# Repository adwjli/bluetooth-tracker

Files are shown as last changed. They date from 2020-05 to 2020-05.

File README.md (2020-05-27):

# Bluetooth Tracker

## Introduction
A Bluetooth Tracker inspired by the Tile Mate Bluetooth Tracker, built around the Nordic nRF51822 Bluetooth transceiver. The device can be programmed to pair with any Android or iOS mobile device via a mobile app.

The design of the trace antenna was provided by Texas Instrument in Application Note AN043. It is an Inverted F Antenna (IFA) with a matched 50 Ohm characteristic impedance at 2.4GHz. The device is capable of up to 4dBm of transmit power.

## Gallery

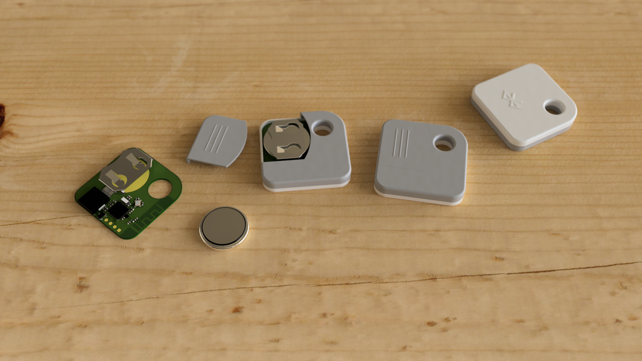
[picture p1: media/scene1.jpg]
Bluetooth Tracker PCB with enclosure.


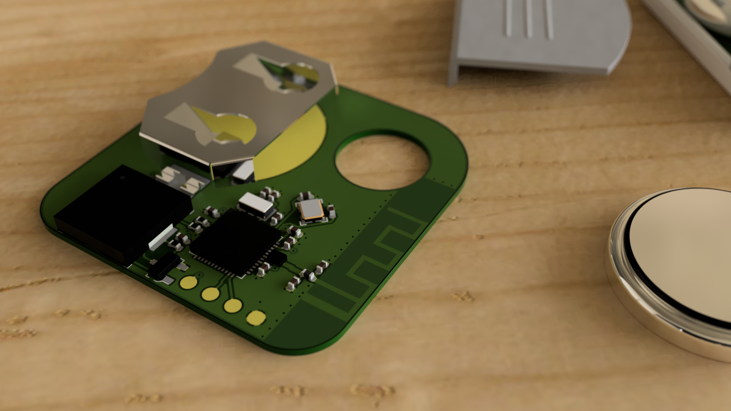
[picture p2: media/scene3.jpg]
Bleutooth Tracker PCB close up.


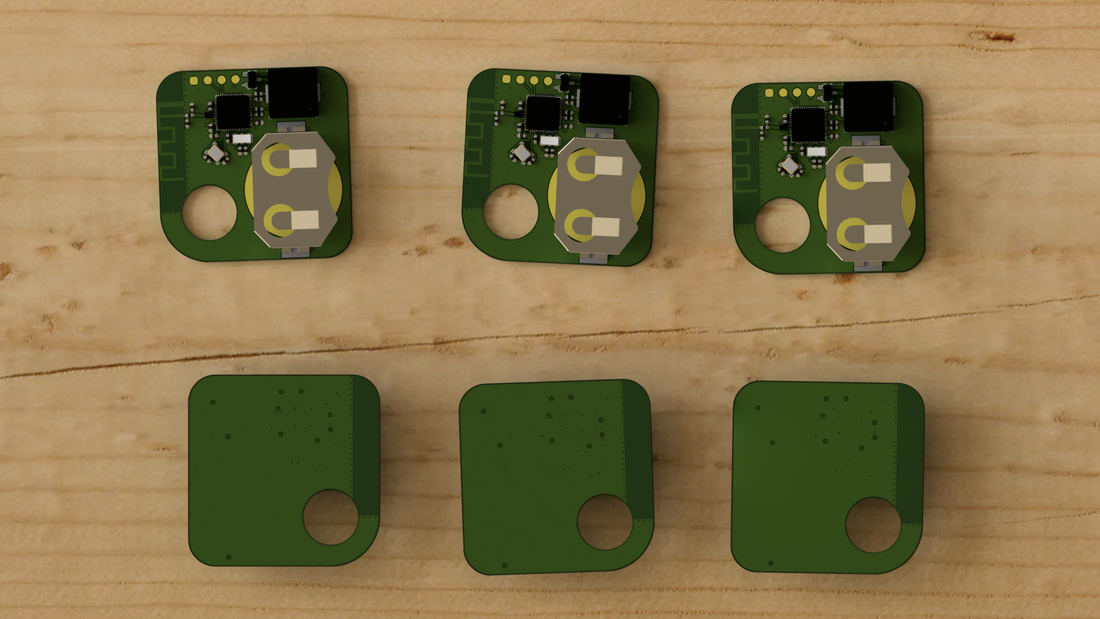
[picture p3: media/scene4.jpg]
Bluetooth Tracker PCB, top and bottom.


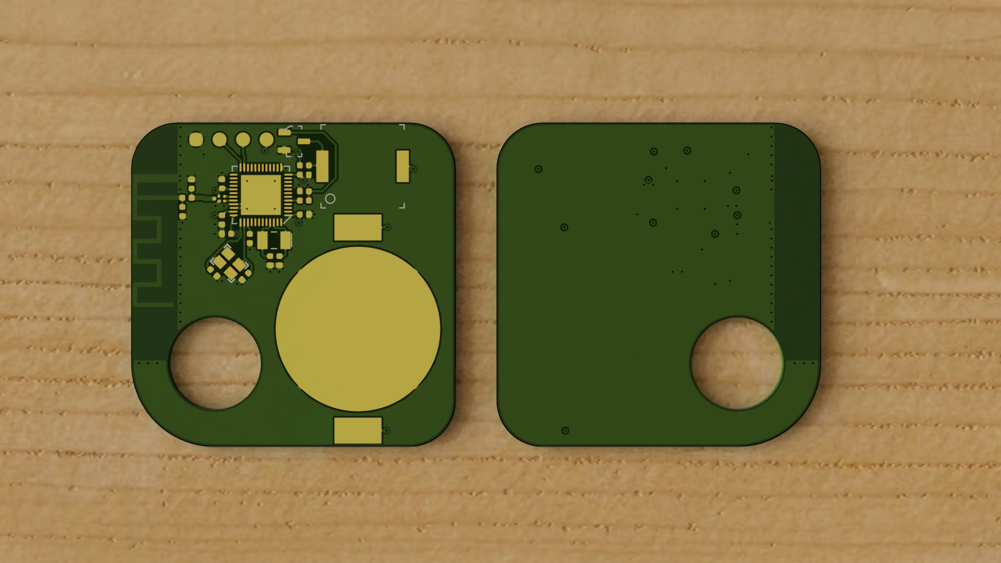
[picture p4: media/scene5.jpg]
Bluetooth Tracker PCB, top and bottom, bare PCB.


## Copper Layers

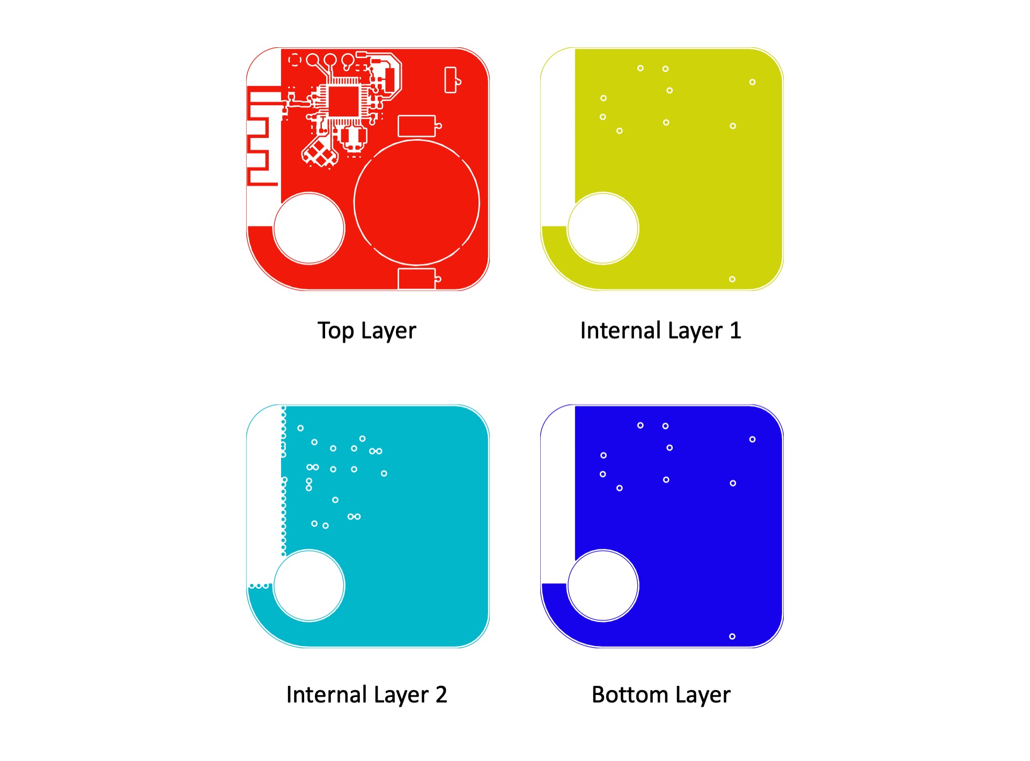
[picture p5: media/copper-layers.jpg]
PCB copper layers.


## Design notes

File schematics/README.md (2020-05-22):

# Schematics

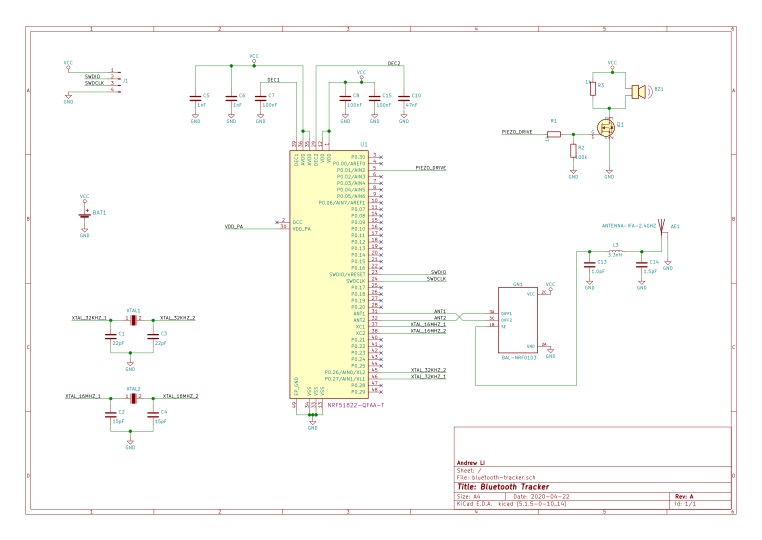
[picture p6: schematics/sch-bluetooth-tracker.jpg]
Schematics.


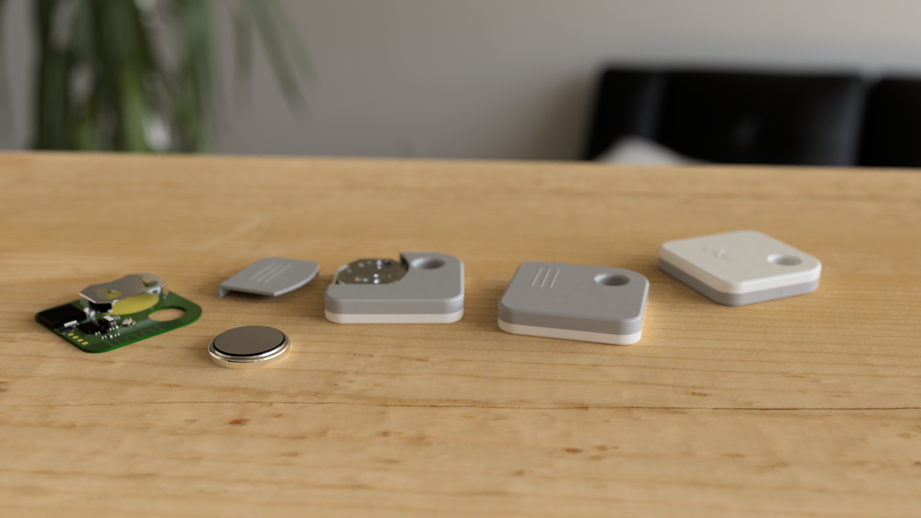
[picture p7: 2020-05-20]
media/scene2.jpg

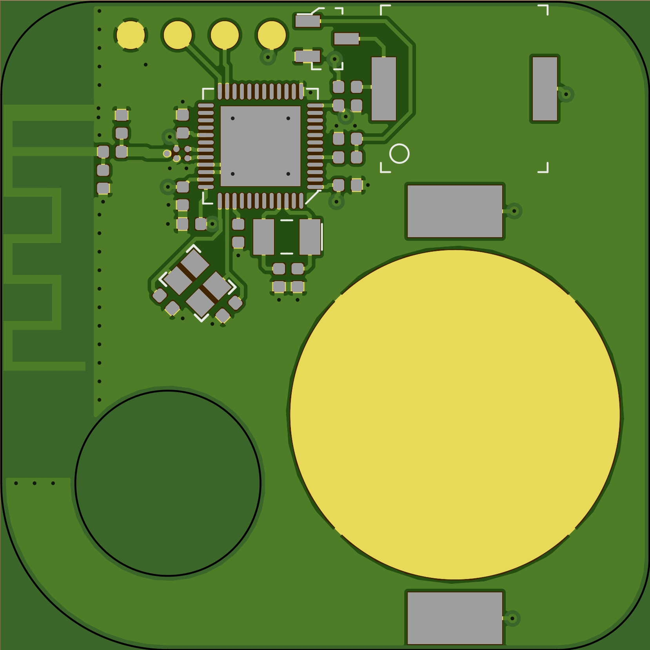
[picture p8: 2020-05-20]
raster/bluetooth-tracker-Front.png

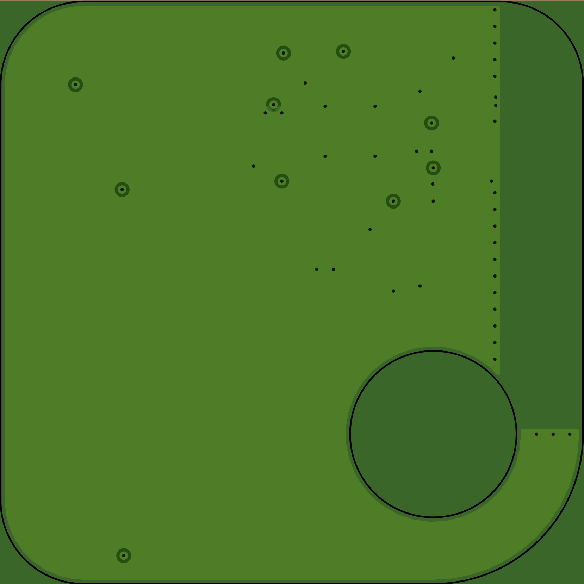
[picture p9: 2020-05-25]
raster/bluetooth-tracker-Back-bare.png

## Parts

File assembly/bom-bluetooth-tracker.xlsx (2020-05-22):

Reference | Quantity | Value | MPN | Manufacturer | Description
BAT1 | 1 | ~ | BK-912 | MPD (Memory Protection Devices) | BATTERY RETAINER COIN 20MM SMD
BZ1 | 1 | ~ | PKMCS0909E4000-R1 | Murata | AUDIO PIEZO TRANSDUCER 12.5V SMD
C1 C3 | 2 | 22pF | GCM1555C1H220FA16D | Murata | CAP CER 22PF 50V C0G/NP0 0402
C10 | 1 | 47nF | GRM155R71H473KE14D | Murata | CAP CER 0.047UF 50V X7R 0402
C13 | 1 | 1.0pF | GCM1555C1H1R0CA16J | Murata | CAP CER 1PF 50V C0G/NP0 0402
C14 | 1 | 1.5pF | GCM1555C1H1R5JA16D | Murata | CAP CER 1.5PF 50V C0G/NP0 0402
C15 C8 C7 | 3 | 100nF | GRM155R71E104KE14J | Murata | CAP CER 0.1UF 25V X7R 0402
C4 C2 | 2 | 15pF | GJM1555C1H150FB01D | Murata | CAP CER 15PF 50V C0G/NP0 0402
C6 C5 | 2 | 1nF | GCM155R71H102KA37D | Murata | CAP CER 1000PF 50V X7R 0402
GN1 | 1 | BAL-NRF01D3 | BAL-NRF01D3 | STMicroelectronics | BALUN 2.4GHZ-2.54GHZ 5WFBGA
L3 | 1 | 3.3nH | LQP15MN3N3W02D | Murata | 3.3nH Unshielded Thick Film Inductor 190mA 400mOhm Max 0402 (1005 Metric)
Q1 | 1 | ~ | FDV301N | ON Semiconductor | MOSFET N-CH 25V 220MA SOT-23
R2 | 1 | 100kΩ | RC0402FR-07100KL | Yageo | RES SMD 100K OHM 1% 1/16W 0402
R3 R1 | 2 | 1kΩ | RC0402FR-071KP | Yageo | RES SMD 1K OHM 1% 1/16W 0402
U1 | 1 | ~ | NRF51822-QFAA-T | Nordic Semiconductor ASA | IC RF TXRX+MCU BLUETOOTH 48VFQFN
XTAL1 | 1 | ~ | ECS-.327-12.5-34B-TR | ECS Inc. | CRYSTAL 32.7680KHZ 12.5PF SMD
XTAL2 | 1 | ~ | NX2520SA-16MHZ-STD-CSW-5 | NDK America, Inc. | CRYSTAL 16.0000MHZ 8PF SMD

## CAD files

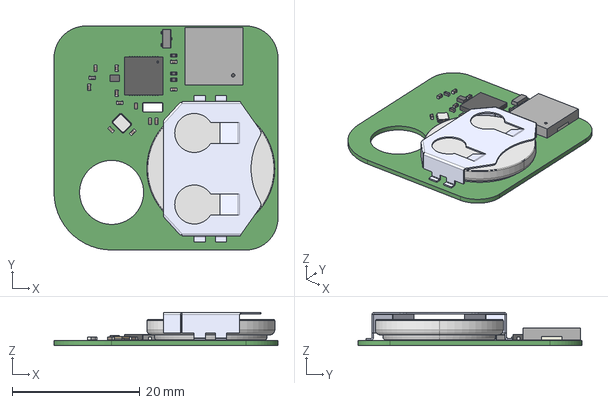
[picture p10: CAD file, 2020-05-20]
step/bluetooth-tracker.step
35.0 x 35.0 x 5.17 mm

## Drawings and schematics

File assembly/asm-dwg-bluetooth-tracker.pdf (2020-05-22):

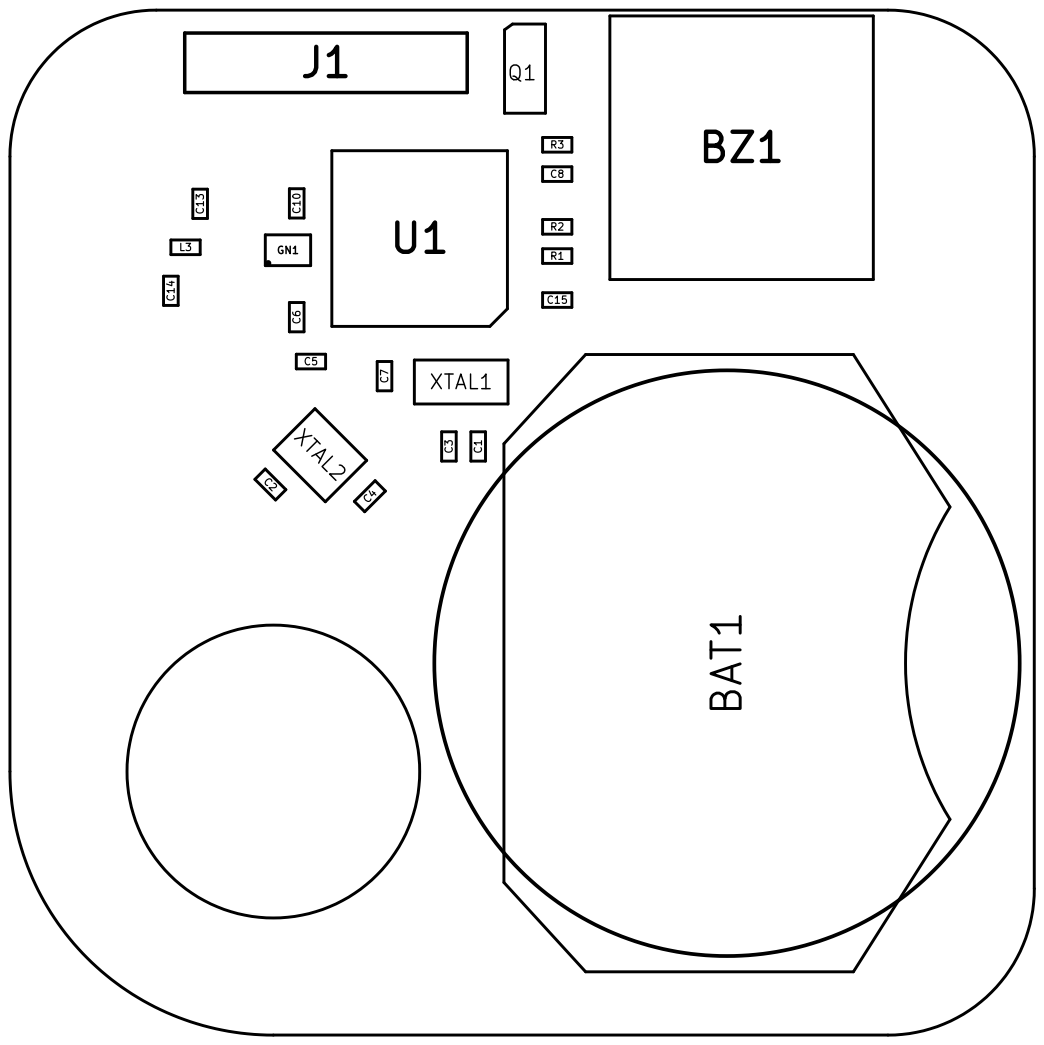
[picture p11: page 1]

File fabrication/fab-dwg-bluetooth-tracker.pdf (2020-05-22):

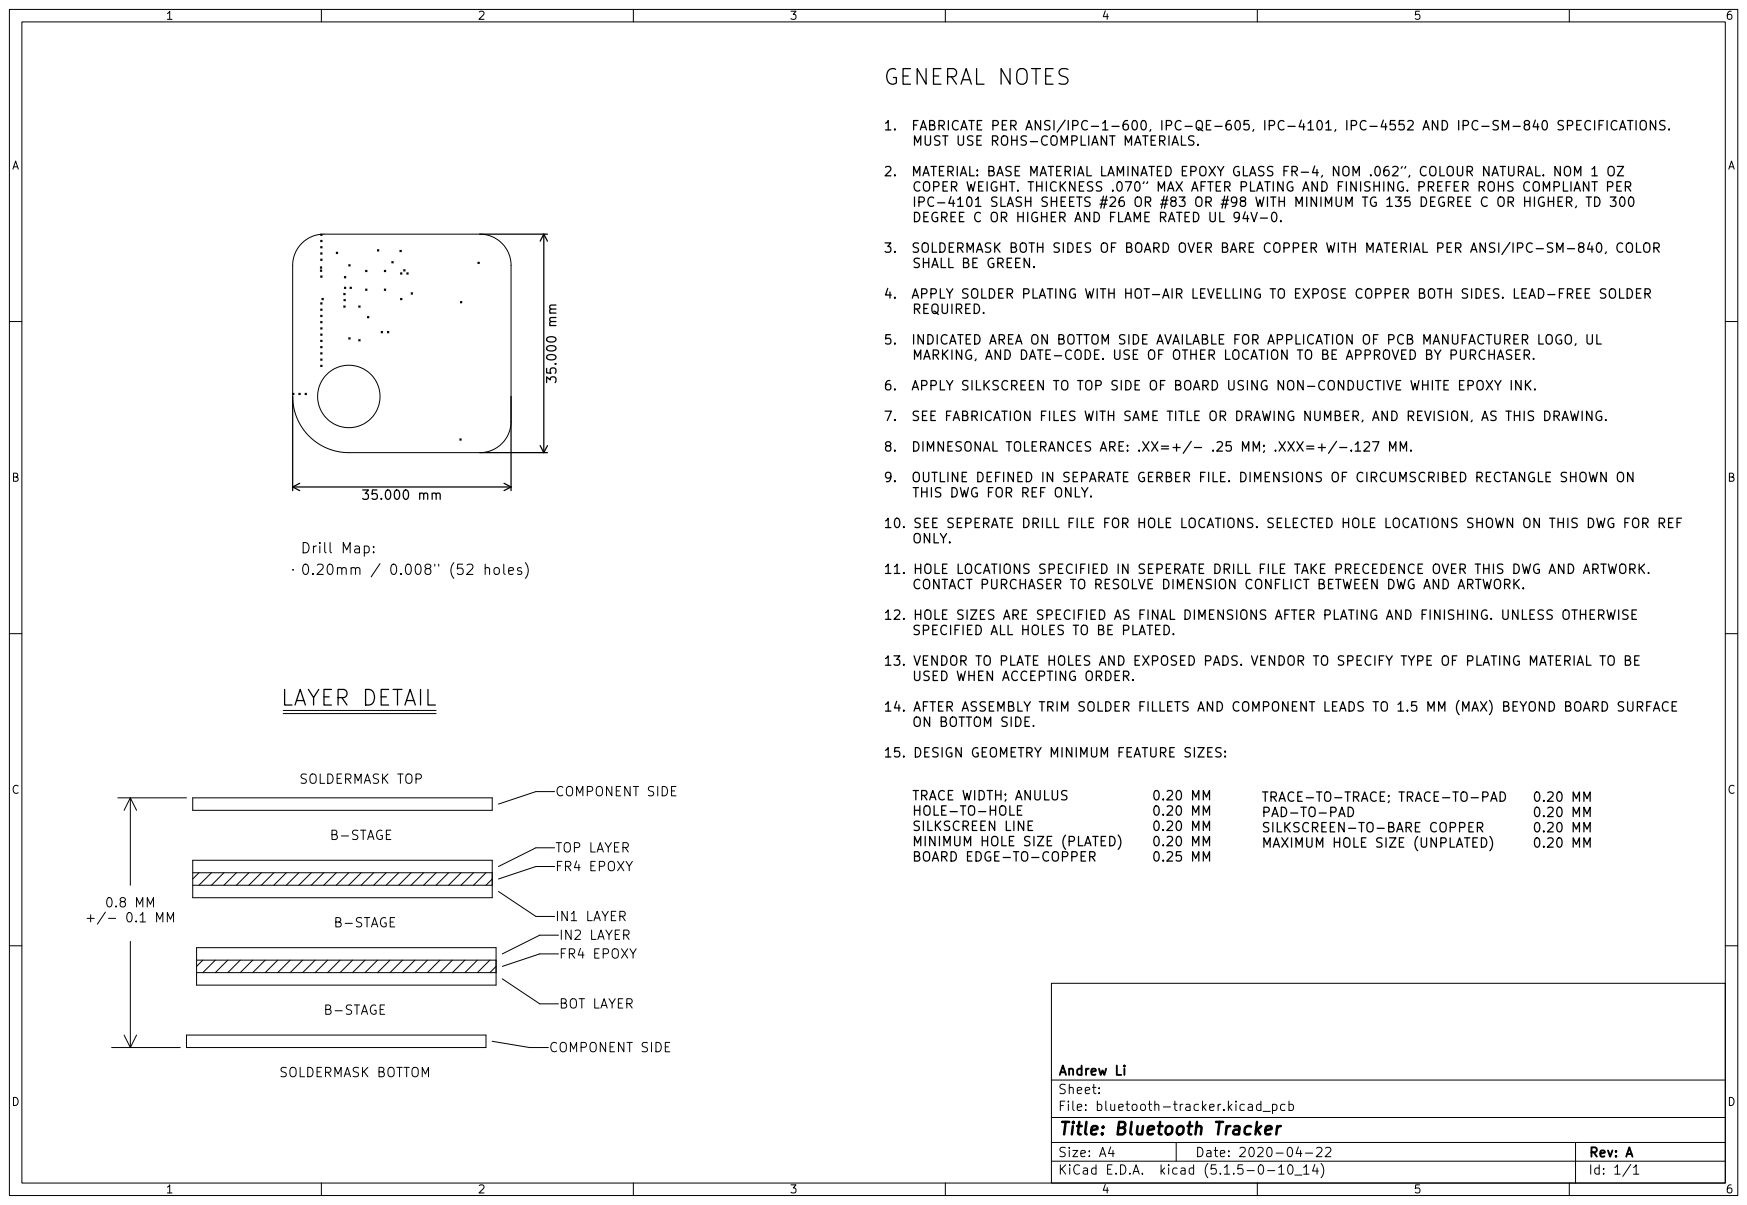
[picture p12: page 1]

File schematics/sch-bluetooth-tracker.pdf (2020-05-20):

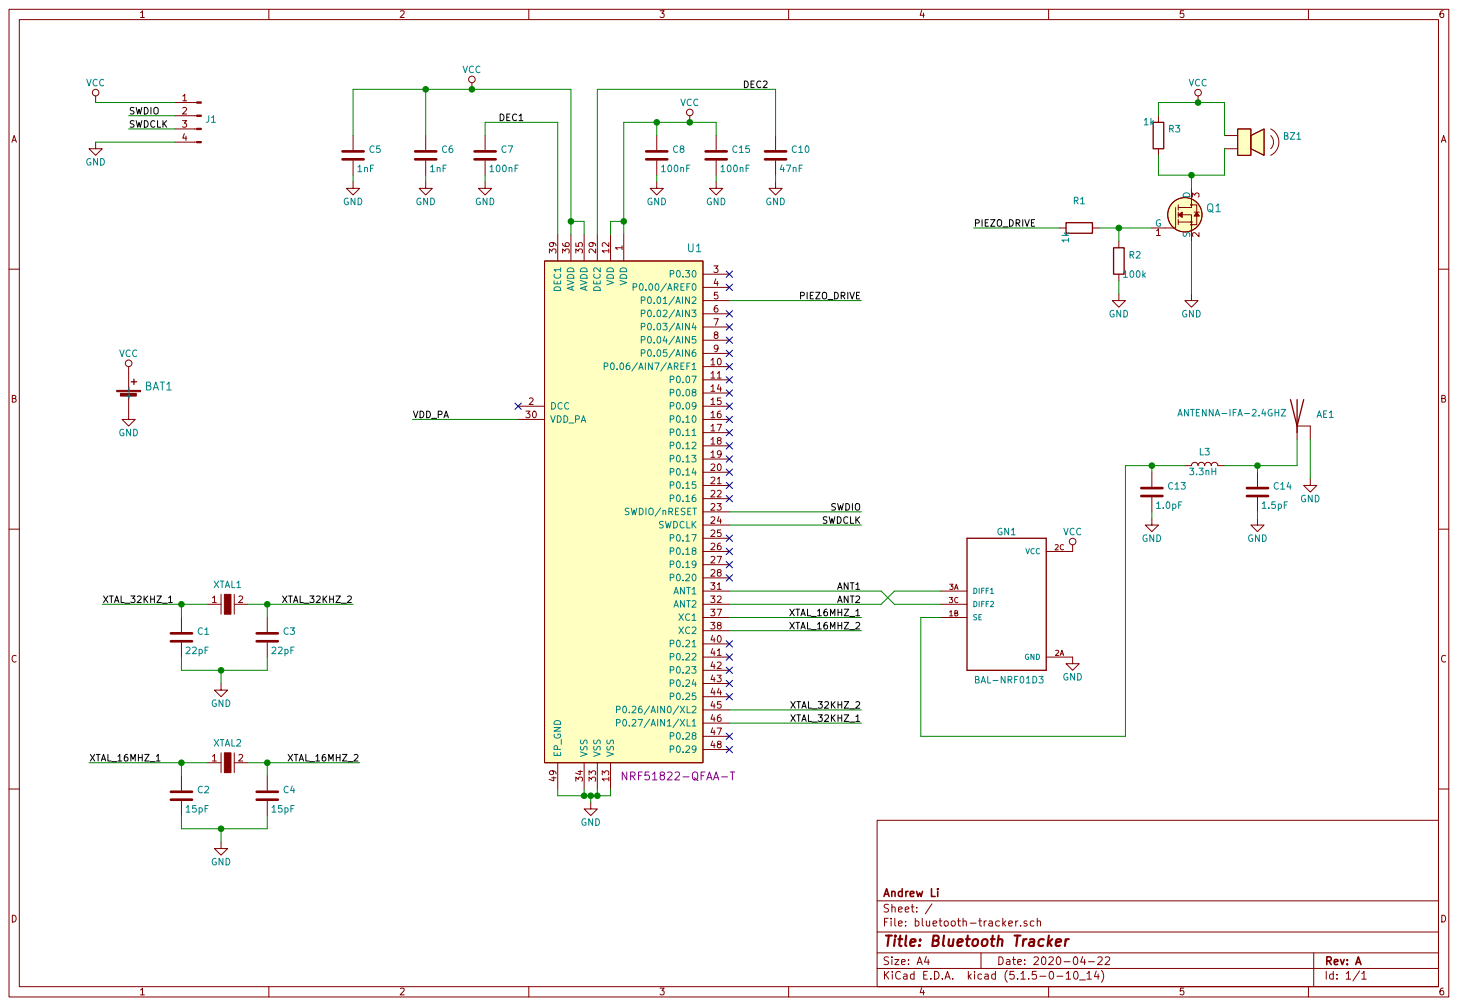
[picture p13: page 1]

1 P0.06/AIN7/AREF1 10 P0.07 11 VDD 12 VSS 13 P0.08 14 P0.09 15 P0.10 16 P0.11 17 P0.12 18 P0.13 19 DCC 2 P0.14 20 P0.15 21 P0.16 22 SWDIO/nRESET 23 SWDCLK 24 P0.17 25 P0.18 26 P0.19 27 P0.20 28 DEC2 29 P0.30 3 VDD_PA 30 ANT1 31 ANT2 32 VSS 33 VSS 34 AVDD 35 AVDD 36 XC1 37 XC2 38 DEC1 39 P0.00/AREF0 4 P0.21 40 P0.22 41 P0.23 42 P0.24 43 P0.25 44 P0.26/AIN0/XL2 45 P0.27/AIN1/XL1 46 P0.28 47 P0.29 48 EP_GND 49 P0.01/AIN2 5 P0.02/AIN3 6 P0.03/AIN4 7 P0.04/AIN5 8 P0.05/AIN6 9 U1 NRF51822-QFAA-T

Id: 1/1 Title: Bluetooth Tracker File: bluetooth-tracker.sch Sheet: / Andrew Li GND

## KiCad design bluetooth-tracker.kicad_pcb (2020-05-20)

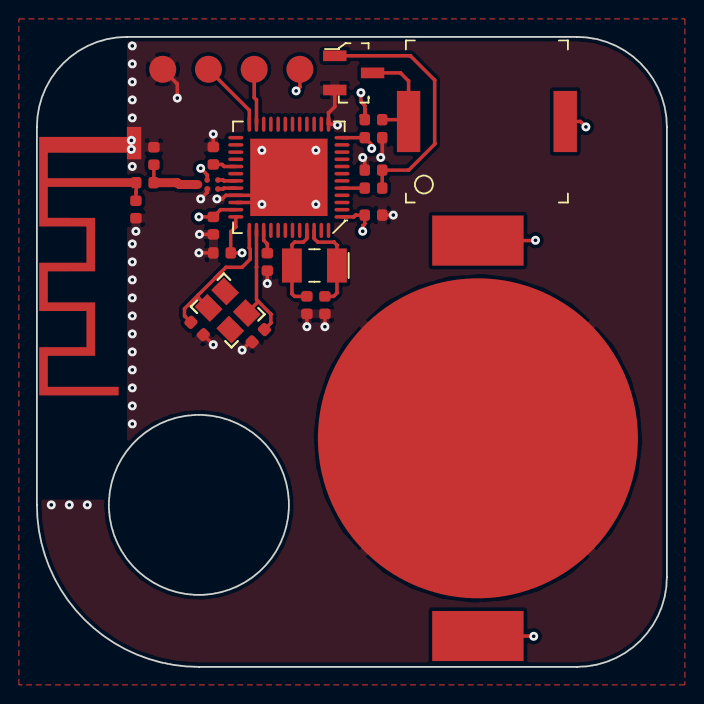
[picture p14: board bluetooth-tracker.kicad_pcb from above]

Board: 4 copper layers, 35.0 x 35.0 mm, 25 parts (0 on the bottom side), 17 nets.

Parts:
AE1: ANTENNA-IFA-2.4GHZ; ANTENNA-IFA-2.4GHZ-2
BAT1: CR2032_CLIP2
BZ1: PKMCS0909E4000-R1; Piezo_9x9mm_PKLCS1212E40A1-R1
C1, C3: 22pF; C_0402_1005Metric
C2, C4: 15pF; C_0402_1005Metric
C5, C6: 1nF; C_0402_1005Metric
C7, C8, C15: 100nF; C_0402_1005Metric
C10: 47nF; C_0402_1005Metric
C13: 1.0pF; C_0402_1005Metric
C14: 1.5pF; C_0402_1005Metric
GN1: BAL-NRF01D3; FCBGA-5N
J1: CONN4PROG
L3: 3.3nH; L_0402_1005Metric
Q1: FDV301N_G; SOT-23-3_G
R1, R3: 1k; R_0402_1005Metric
R2: 100k; R_0402_1005Metric
U1: NRF51822-QFAA-T_G; QFN-48-1EP_6x6mmG
XTAL1: ECS-_327-12_5-34B-TR; SMD-2_3.2x1.5mmG
XTAL2: NX2520SA-16MHZ-STD-CSW-5; SOIC254P1016X440-4N

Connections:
/ANT1: GN1.3C, U1.31
/ANT2: GN1.3A, U1.32
/DEC1: C7.1, U1.39
/DEC2: C10.1, U1.29
/PIEZO_DRIVE: R1.2, U1.5
/SWDCLK: J1.3, U1.24
/SWDIO: J1.2, U1.23
/XTAL_16MHZ_1: C2.1, U1.37, XTAL2.1
/XTAL_16MHZ_2: C4.1, U1.38, XTAL2.2
/XTAL_32KHZ_1: C1.1, U1.46, XTAL1.1
/XTAL_32KHZ_2: C3.1, U1.45, XTAL1.2
GND: AE1.2, BAT1.2, C1.2, C2.2, C3.2, C4.2, C5.2, C6.2, C7.2, C8.2, C10.2, C13.2, C14.2, C15.2, GN1.2A, J1.4, Q1.2, R2.2, U1.13, U1.33, U1.34, U1.49
unnamed: AE1.1, C14.1, L3.2
unnamed: BZ1.2, Q1.3, R3.1
unnamed: C13.1, GN1.1B, L3.1
unnamed: Q1.1, R1.1, R2.1
VCC: BAT1.1, BZ1.1, C5.1, C6.1, C8.1, C15.1, GN1.2C, J1.1, R3.2, U1.1, U1.12, U1.35, U1.36

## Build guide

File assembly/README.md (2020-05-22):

# Assembly Drawing

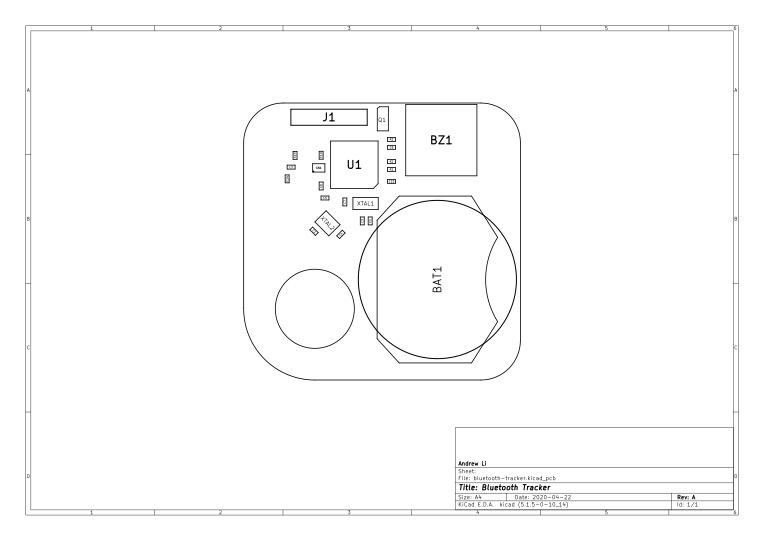
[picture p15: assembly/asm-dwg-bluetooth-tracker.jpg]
Assembly drawing.


# Bill of Materials
| Reference  	|  Quantity 	|  Value 	|  MPN 	|  Manufacturer 	|  Description 	|
|---	|---	|---	|---	|---	|---	|
| BAT1 	| 1 	| ~ 	| BK-912 	| MPD (Memory Protection Devices) 	| BATTERY RETAINER COIN 20MM SMD 	|
| BZ1 	| 1 	| ~ 	| PKMCS0909E4000-R1 	| Murata 	| AUDIO PIEZO TRANSDUCER 12.5V SMD 	|
| C1 C3 	| 2 	| 22pF 	| GCM1555C1H220FA16D 	| Murata 	| CAP CER 22PF 50V C0G/NP0 0402 	|
| C10 	| 1 	| 47nF 	| GRM155R71H473KE14D 	| Murata 	| CAP CER 0.047UF 50V X7R 0402 	|
| C13 	| 1 	| 1.0pF 	| GCM1555C1H1R0CA16J 	| Murata 	| CAP CER 1PF 50V C0G/NP0 0402 	|
| C14 	| 1 	| 1.5pF 	| GCM1555C1H1R5JA16D 	| Murata 	| CAP CER 1.5PF 50V C0G/NP0 0402 	|
| C15 C8 C7  	| 3 	| 100nF 	| GRM155R71E104KE14J 	| Murata 	| CAP CER 0.1UF 25V X7R 0402 	|
| C4 C2 	| 2 	| 15pF 	| GJM1555C1H150FB01D 	| Murata 	| CAP CER 15PF 50V C0G/NP0 0402 	|
| C6 C5 	| 2 	| 1nF 	| GCM155R71H102KA37D 	| Murata 	| CAP CER 1000PF 50V X7R 0402 	|
| GN1 	| 1 	| BAL-NRF01D3 	| BAL-NRF01D3 	| STMicroelectronics 	| BALUN 2.4GHZ-2.54GHZ 5WFBGA 	|
| L3 	| 1 	| 3.3nH 	| LQP15MN3N3W02D 	| Murata 	| 3.3nH Unshielded Thick Film Inductor 190mA 400mOhm Max 0402 (1005 Metric) 	|
| Q1 	| 1 	| ~ 	| FDV301N 	| ON Semiconductor 	| MOSFET N-CH 25V 220MA SOT-23 	|
| R2 	| 1 	| 100kΩ 	| RC0402FR-07100KL 	| Yageo 	| RES SMD 100K OHM 1% 1/16W 0402 	|
| R3 R1 	| 2 	| 1kΩ 	| RC0402FR-071KP 	| Yageo 	| RES SMD 1K OHM 1% 1/16W 0402 	|
| U1 	| 1 	| ~ 	| NRF51822-QFAA-T 	| Nordic Semiconductor ASA 	| IC RF TXRX+MCU BLUETOOTH 48VFQFN 	|
| XTAL1 	| 1 	| ~ 	| ECS-.327-12.5-34B-TR 	| ECS Inc. 	| CRYSTAL 32.7680KHZ 12.5PF SMD 	|
| XTAL2 	| 1 	| ~ 	| NX2520SA-16MHZ-STD-CSW-5 	| NDK America, Inc. 	| CRYSTAL 16.0000MHZ 8PF SMD 	|

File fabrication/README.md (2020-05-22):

# Fabrication Drawing

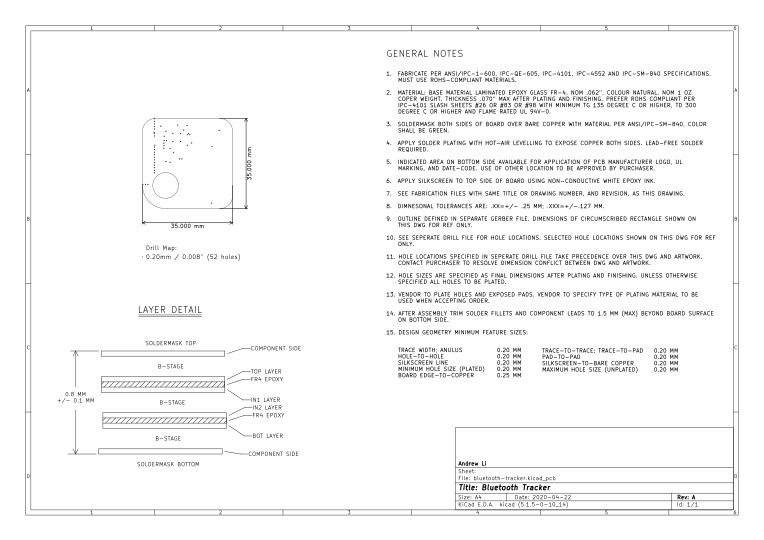
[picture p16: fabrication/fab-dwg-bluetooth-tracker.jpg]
Fabrication drawing.


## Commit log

2020-05-15 First commit.
    [bluetooth-tracker.kicad_pcb, bluetooth-tracker.sch, bluetooth-tracker.stp]
2020-05-20 Commiting finished design files.
    [bluetooth-tracker-B_Cu.gbr, bluetooth-tracker-B_Mask.gbr, bluetooth-tracker-B_Paste.gbr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]
2020-05-20 Replotted Gerbers, updated PCB design so that origin is at the hole.
    [bluetooth-tracker-B_Cu.gbr, bluetooth-tracker-B_Mask.gbr, bluetooth-tracker-B_Paste.gbr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]
2020-05-20 Added an image of the copper layers.
    [bluetooth-tracker.kicad_pcb]
2020-05-22 Adding assembly jpg.
2020-05-22 Updating README.md in assembly folder.
    [bom-bluetooth-tracker.xlsx]
2020-05-22 Adding schematics drawing.
2020-05-22 Updating the image of the PCB layers in README.md.
